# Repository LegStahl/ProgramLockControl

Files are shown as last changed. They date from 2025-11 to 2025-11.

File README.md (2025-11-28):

# ProgramLockControl
## Description
This device is supposed to use for controlling the door. It can open the door if the right IButton is pressed, also it has a button to open the door.
Device controls magnetic lock. Internally device can coolect info about opening the door, for example: key number, time of enter and etc.
Also device can another control high current till 5A load. This connection is supposed to be used for LED strip.
## Microcontroller and power schema V1.0
In the image below schema of the mcu and power.
<div style="text-align: center;">
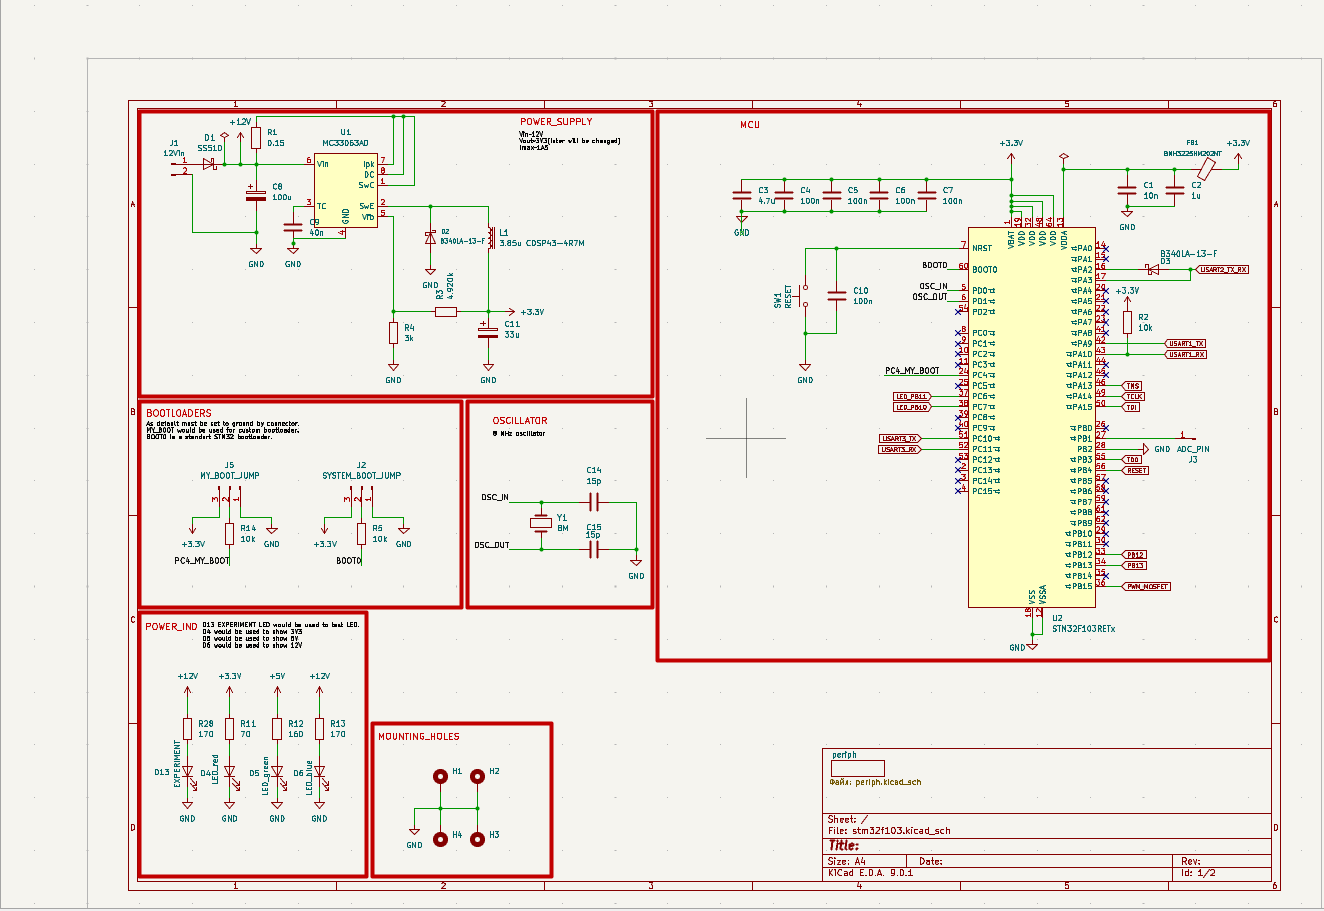
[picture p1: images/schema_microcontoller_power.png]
HTML Image
    
</div>

## Peripheria V1.0
In the image below schema of peripherias of MCU.
<div style="text-align: center;">
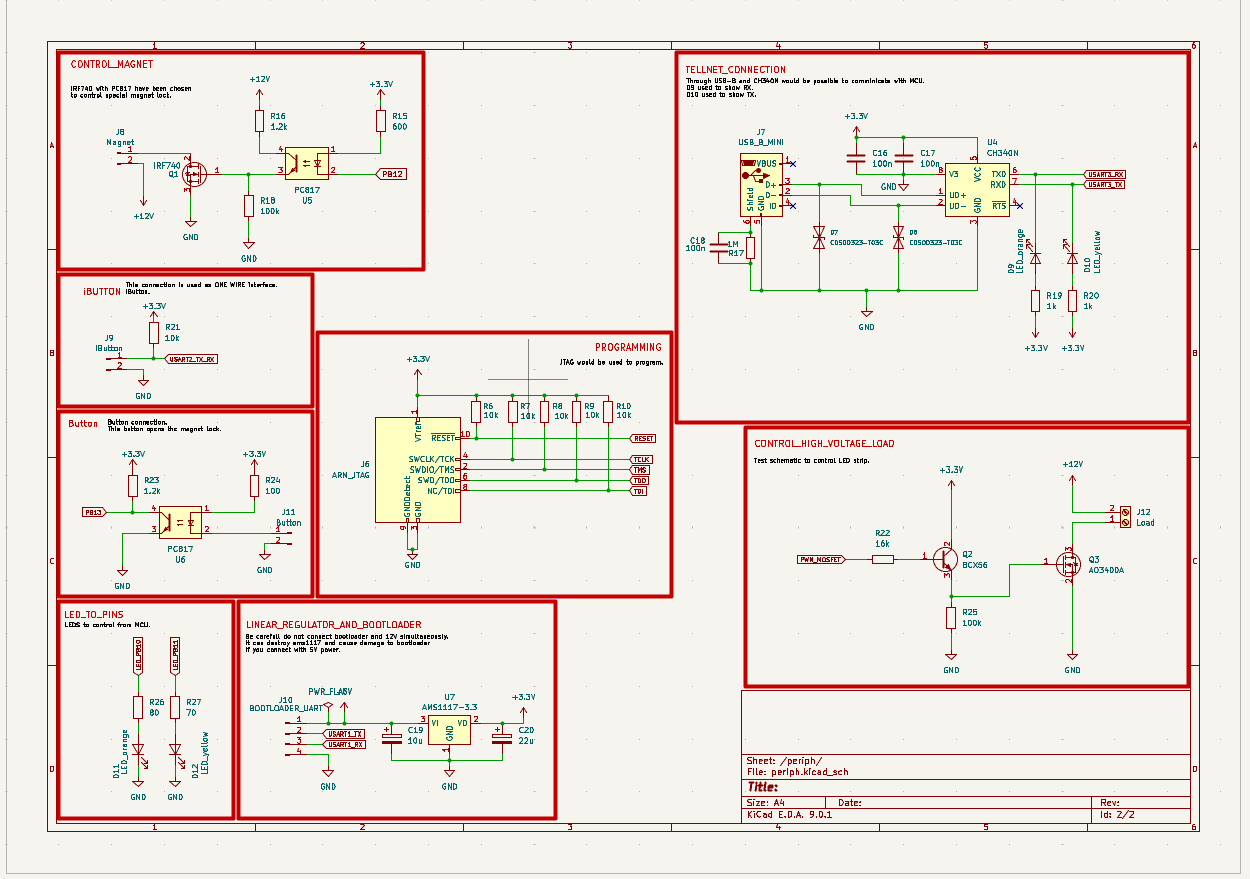
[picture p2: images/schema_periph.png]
HTML Image
    
</div>

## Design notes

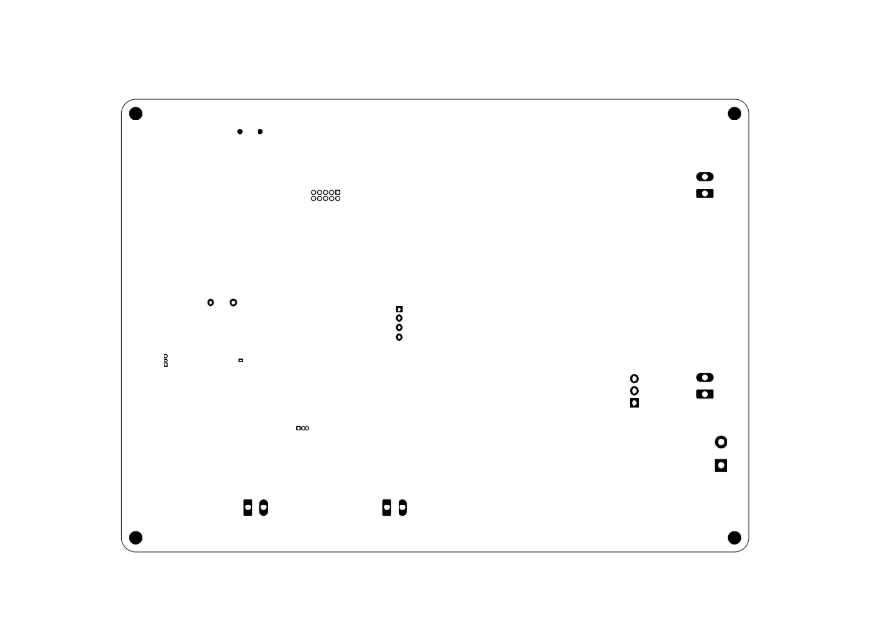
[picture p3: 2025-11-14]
images/Bottom_V1.png

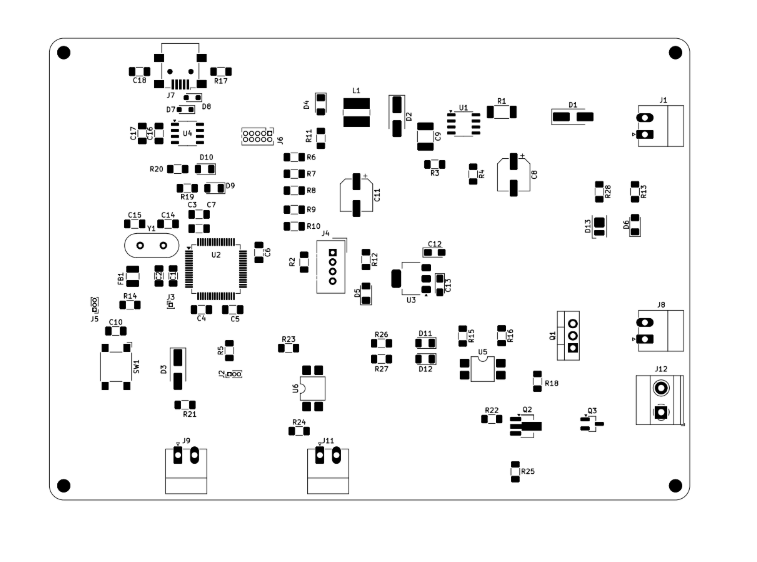
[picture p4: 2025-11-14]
images/Front_V1.png

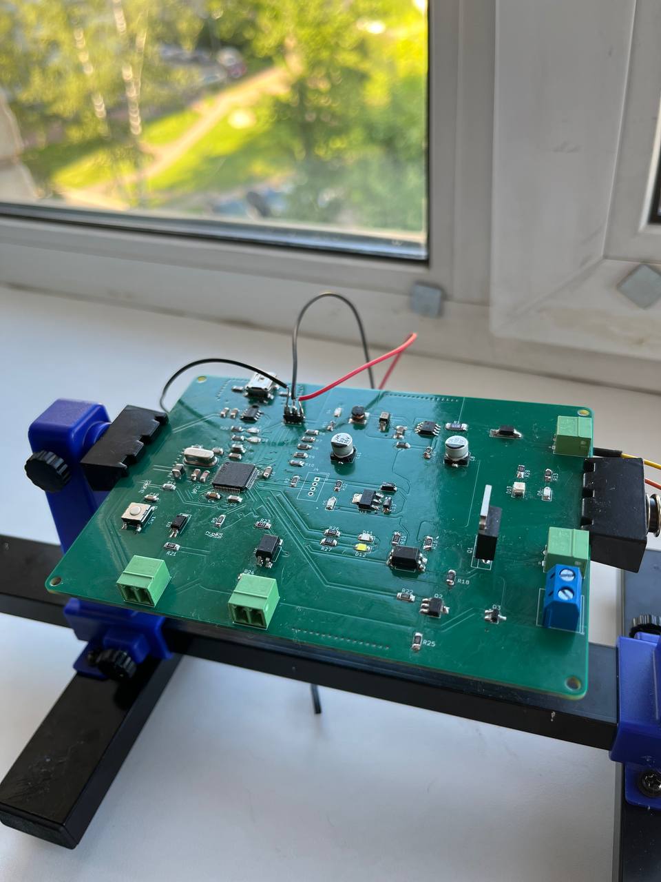
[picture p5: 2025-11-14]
images/device_V1.jpg

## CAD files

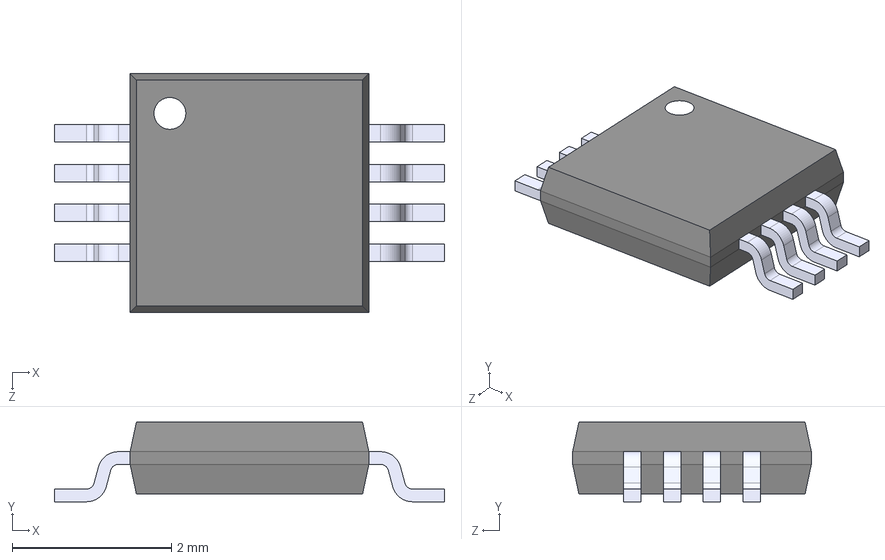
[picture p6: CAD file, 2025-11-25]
CH340N/CH340N.step
4.90 x 1 x 3.00 mm

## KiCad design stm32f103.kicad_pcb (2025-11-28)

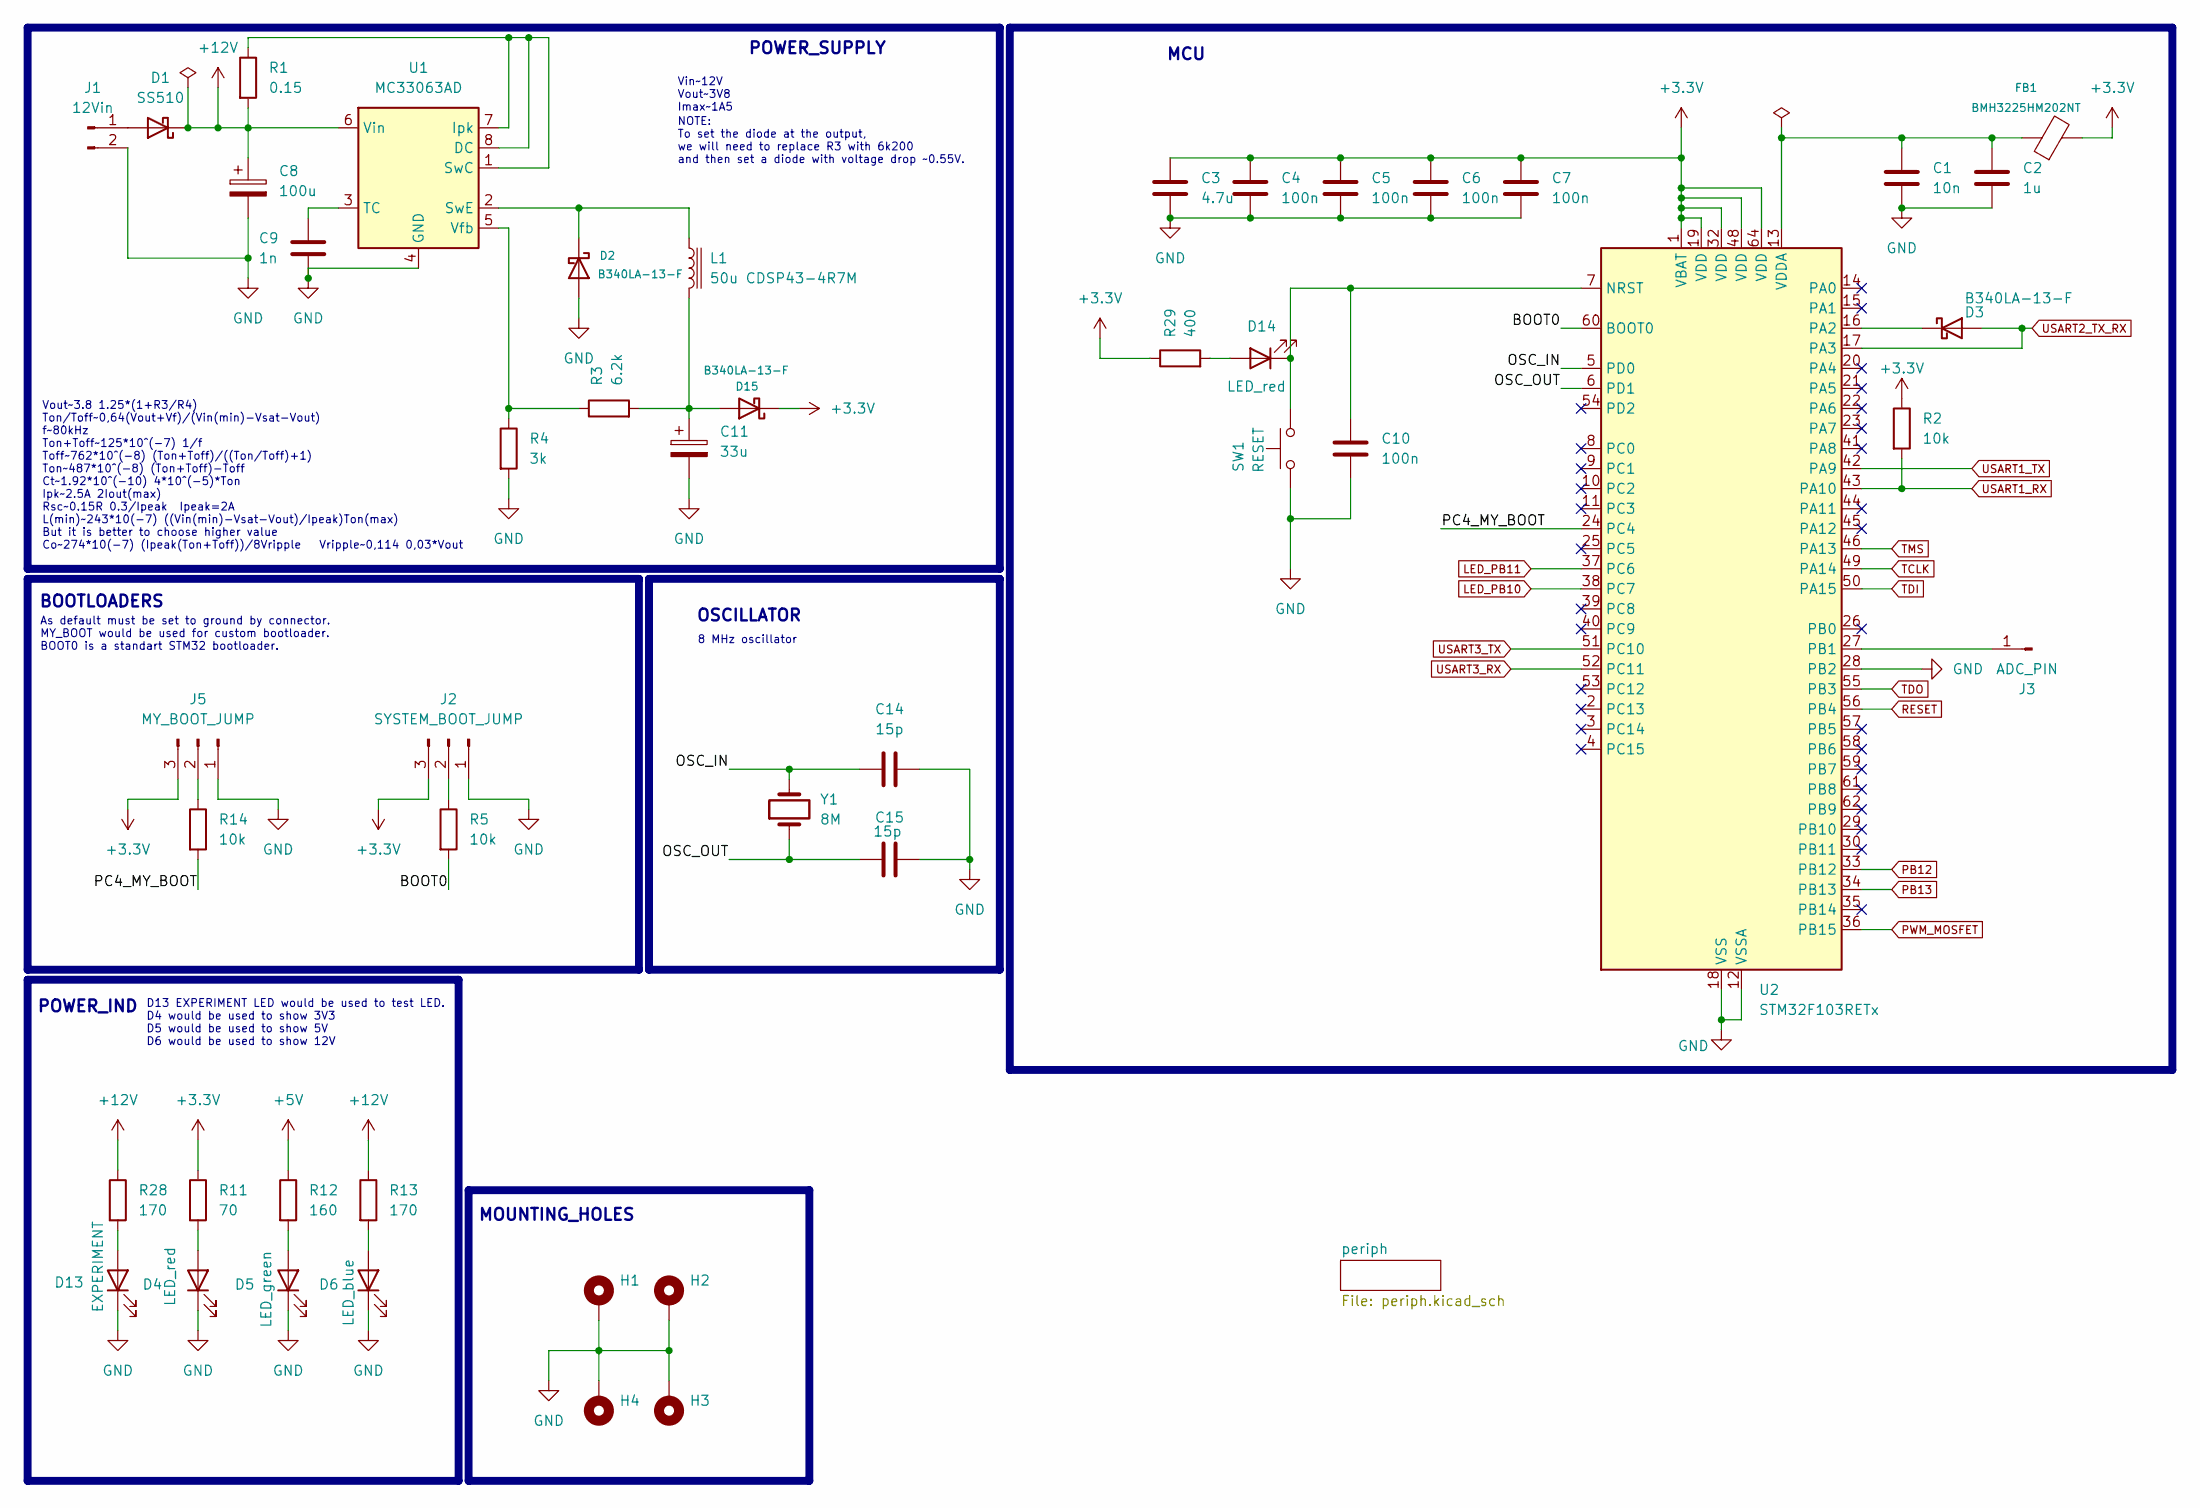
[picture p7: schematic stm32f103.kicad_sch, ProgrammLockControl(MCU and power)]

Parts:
C1: 10n; C_1206_3216Metric_Pad1.33x1.80mm_HandSolder
C2: 1u; C_1206_3216Metric_Pad1.33x1.80mm_HandSolder
C3: 4.7u; C_1206_3216Metric_Pad1.33x1.80mm_HandSolder
C4, C5, C6, C7, C10: 100n; C_1206_3216Metric_Pad1.33x1.80mm_HandSolder
C8: 100u; CP_Elec_6.3x5.4
C9: 1n; C_1812_4532Metric_Pad1.57x3.40mm_HandSolder
C11: 33u; CP_Elec_6.3x5.4
C14, C15: 15p; C_1206_3216Metric_Pad1.33x1.80mm_HandSolder
D1: SS510; D_SMA_Handsoldering
D2, D3, D15: B340LA-13-F; D_SMA_Handsoldering
D4, D14: LED_red; LED_1206_3216Metric_Pad1.42x1.75mm_HandSolder
D5: LED_green; LED_1206_3216Metric_Pad1.42x1.75mm_HandSolder
D6: LED_blue; LED_1206_3216Metric_Pad1.42x1.75mm_HandSolder
D13: EXPERIMENT; LED_Everlight-SMD3528_3.5x2.8mm_67-21ST
FB1: BMH3225HM202NT; L_1210_3225Metric_Pad1.42x2.65mm_HandSolder
H1, H2, H3, H4: MountingHole_Pad; MountingHole_3.2mm_M3_Pad_Via
J1: 12Vin; PhoenixContact_MC_1,5_2-G-3.5_1x02_P3.50mm_Horizontal
J2: SYSTEM_BOOT_JUMP; PinHeader_1x03_P2.54mm_Vertical
J3: ADC_PIN; PinHeader_1x01_P2.54mm_Vertical
J5: MY_BOOT_JUMP; PinHeader_1x03_P2.54mm_Vertical
L1: 50u CDSP43-4R7M; L_TracoPower_TCK-047_5.2x5.8mm
R1: 0.15; R_2010_5025Metric_Pad1.40x2.65mm_HandSolder
R2, R5, R14: 10k; R_1206_3216Metric_Pad1.30x1.75mm_HandSolder
R3: 6.2k; R_1206_3216Metric_Pad1.30x1.75mm_HandSolder
R4: 3k; R_1206_3216Metric_Pad1.30x1.75mm_HandSolder
R11: 70; R_1206_3216Metric_Pad1.30x1.75mm_HandSolder
R12: 160; R_1206_3216Metric_Pad1.30x1.75mm_HandSolder
R13, R28: 170; R_1206_3216Metric_Pad1.30x1.75mm_HandSolder
R29: 400; R_1206_3216Metric_Pad1.30x1.75mm_HandSolder
SW1: RESET; SW_SPST_Omron_B3FS-100xP
U1: MC33063AD; SO-8_3.9x4.9mm_P1.27mm
U2: STM32F103RETx; LQFP-64_10x10mm_P0.5mm
Y1: 8M; Crystal_HC49-4H_Vertical

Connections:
+3.3V: C3.1, C4.1, C5.1, C6.1, C7.1, D15.1 (K), FB1.2, J2.3, J5.3, R2.1, R11.1, R29.1, U2.1 (VBAT), U2.19 (VDD), U2.32 (VDD), U2.48 (VDD), U2.64 (VDD); also elsewhere on the board
+5V: R12.1; also elsewhere on the board
+12V: C8.1, D1.1 (K), R1.2, R13.1, R28.1, U1.6 (Vin); also elsewhere on the board
/BOOT0: R5.2, U2.60 (BOOT0)
/OSC_IN: C14.1, U2.5 (PD0), Y1.2
/OSC_OUT: C15.1, U2.6 (PD1), Y1.1
/PC4_MY_BOOT: R14.2, U2.24 (PC4)
GND: C1.2, C2.2, C3.2, C4.2, C5.2, C6.2, C7.2, C8.2, C9.2, C10.2, C11.2, C14.2, C15.2, D2.2 (A), D4.1 (K), D5.1 (K), D6.1 (K), D13.1 (K), H1.1, H2.1, H3.1, H4.1, J1.2, J2.1, J5.1, R4.2, SW1.1, U1.4 (GND), U2.12 (VSSA), U2.18 (VSS), U2.28 (PB2), U2.31 (VSS), U2.47 (VSS), U2.63 (VSS); also elsewhere on the board
LED_PB10: U2.38 (PC7); also elsewhere on the board
LED_PB11: U2.37 (PC6); also elsewhere on the board
unnamed: D1.2 (A), J1.1
unnamed: D2.1 (K), L1.1, U1.2 (SwE)
unnamed: D3.1 (K), U2.16 (PA2)
unnamed: D4.2 (A), R11.2
unnamed: D5.2 (A), R12.2
unnamed: D6.2 (A), R13.2
unnamed: D13.2 (A), R28.2
unnamed: D14.2 (A), R29.2
unnamed: C10.1, D14.1 (K), SW1.2, U2.7 (NRST)
unnamed: C11.1, D15.2 (A), L1.2, R3.2
unnamed: J2.2, R5.1
unnamed: J3.1, U2.27 (PB1)
unnamed: J5.2, R14.1
unnamed: R1.1, U1.1 (SwC), U1.7 (Ipk), U1.8 (DC)
unnamed: C9.1, U1.3 (TC)
unnamed: R3.1, R4.1, U1.5 (Vfb)
unnamed: C1.1, C2.1, FB1.1, U2.13 (VDDA)
PB12: U2.33 (PB12); also elsewhere on the board
PB13: U2.34 (PB13); also elsewhere on the board
PWM_MOSFET: U2.36 (PB15); also elsewhere on the board
RESET: U2.56 (PB4); also elsewhere on the board
TCLK: U2.49 (PA14); also elsewhere on the board
TDI: U2.50 (PA15); also elsewhere on the board
TDO: U2.55 (PB3); also elsewhere on the board
TMS: U2.46 (PA13); also elsewhere on the board
USART1_RX: R2.2, U2.43 (PA10); also elsewhere on the board
USART1_TX: U2.42 (PA9); also elsewhere on the board
USART2_TX_RX: D3.2 (A), U2.17 (PA3); also elsewhere on the board
USART3_RX: U2.52 (PC11); also elsewhere on the board
USART3_TX: U2.51 (PC10); also elsewhere on the board

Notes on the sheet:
Vin~12V Vout~3V8 Imax~1A5
MOUNTING_HOLES
D13 EXPERIMENT LED would be used to test LED. D4 would be used to show 3V3 D5 would be used to show 5V D6 would be used to show 12V
POWER_IND
MCU
NOTE: To set the diode at the output, we will need to replace R3 with 6k200 and then set a diode with voltage drop ~0.55V.
Vout~3.8 1.25*(1+R3/R4) Ton/Toff~0,64(Vout+Vf)/(Vin(min)-Vsat-Vout) f~80kHz Ton+Toff~125*10^(-7) 1/f Toff~762*10^(-8) (Ton+Toff)/((Ton/Toff)+1) Ton~487*10^(-8) (Ton+Toff)-Toff Ct~1.92*10^(-10) 4*10^(-5)*Ton Ipk~2.5A 2Iout(max) Rsc~0.15R 0.3/Ipeak Ipeak=2A L(min)~243*10(-7) ((Vin(min)-Vsat-Vout)/Ipe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
OSCILLATOR
BOOTLOADERS
As default must be set to ground by connector. MY_BOOT would be used for custom bootloader. BOOT0 is a standart STM32 bootloader.
POWER_SUPPLY
8 MHz oscillator

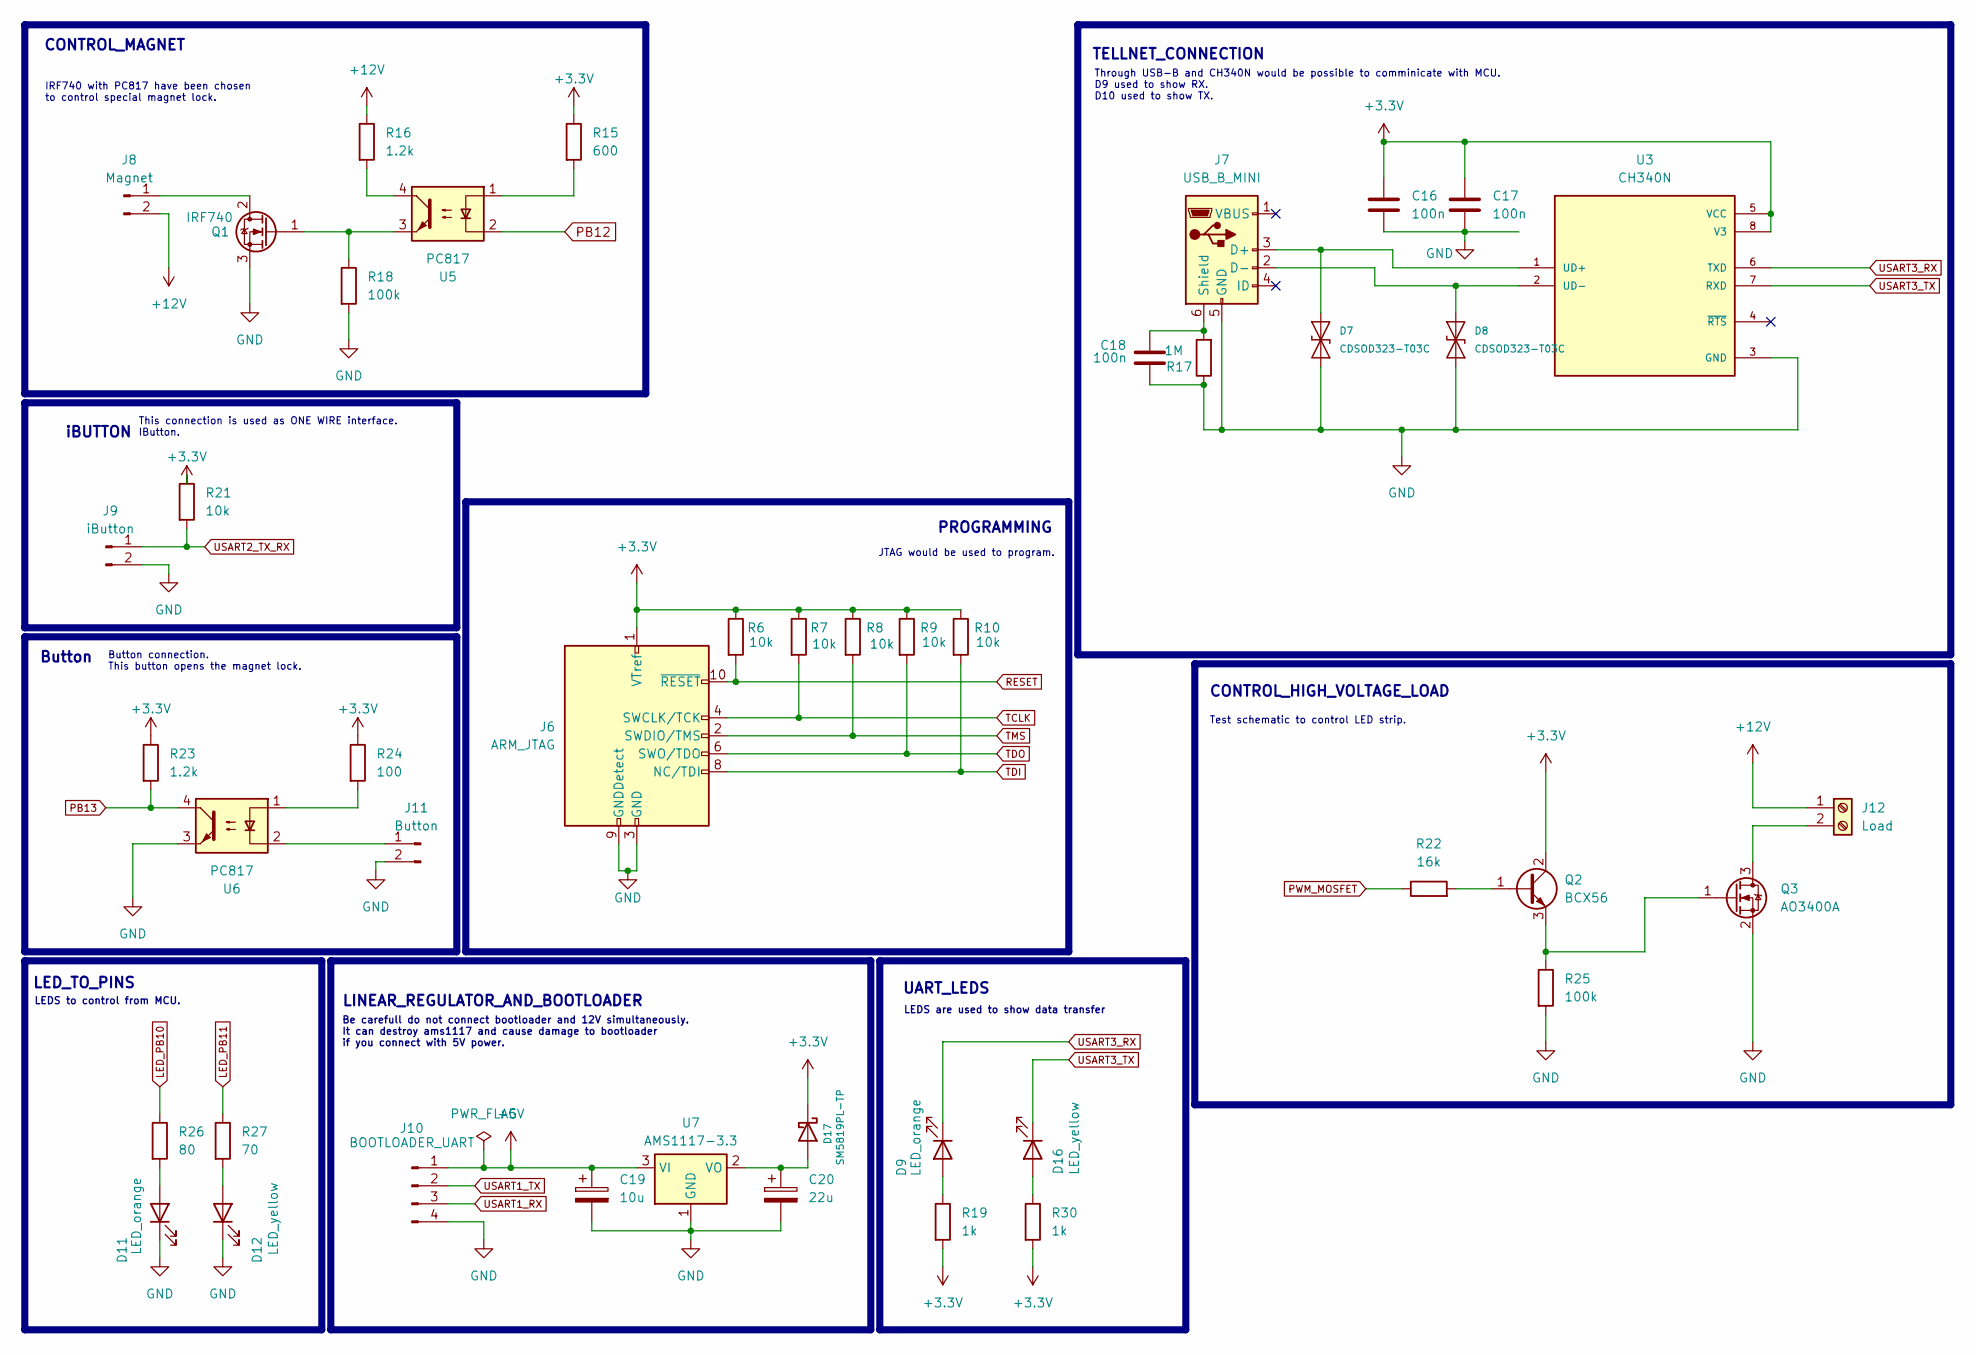
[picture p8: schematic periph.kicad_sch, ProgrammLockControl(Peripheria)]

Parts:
C16, C17, C18: 100n; C_1206_3216Metric_Pad1.33x1.80mm_HandSolder
C19: 10u; CP_EIA-3216-12_Kemet-S_HandSolder
C20: 22u; CP_EIA-3216-12_Kemet-S_HandSolder
D7, D8: CDSOD323-T03C; D_SOD-323_HandSoldering
D9, D11: LED_orange; LED_1206_3216Metric
D12, D16: LED_yellow; LED_1206_3216Metric
D17: SM5819PL-TP; D_SOD-123F
J6: ARM_JTAG; PinHeader_2x05_P2.54mm_Vertical
J7: USB_B_MINI; USB_Mini-B_Lumberg_2486_01_Horizontal
J8: Magnet; PhoenixContact_MC_1,5_2-G-3.5_1x02_P3.50mm_Horizontal
J9: iButton; PhoenixContact_MC_1,5_2-G-3.5_1x02_P3.50mm_Horizontal
J10: BOOTLOADER_UART; PinHeader_1x04_P2.54mm_Vertical
J11: Button; PhoenixContact_MC_1,5_2-G-3.5_1x02_P3.50mm_Horizontal
J12: Load; TerminalBlock_Phoenix_MKDS-1,5-2-5.08_1x02_P5.08mm_Horizont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
Q1: IRF740; TO-220-3_Vertical
Q2: BCX56; SOT-89-3_Handsoldering
Q3: AO3400A; SOT-23_Handsoldering
R6, R7, R8, R9, R10, R21: 10k; R_1206_3216Metric_Pad1.30x1.75mm_HandSolder
R15: 600; R_1206_3216Metric_Pad1.30x1.75mm_HandSolder
R16, R23: 1.2k; R_1206_3216Metric_Pad1.30x1.75mm_HandSolder
R17: 1M; R_1206_3216Metric_Pad1.30x1.75mm_HandSolder
R18, R25: 100k; R_1206_3216Metric_Pad1.30x1.75mm_HandSolder
R19, R30: 1k; R_1206_3216Metric_Pad1.30x1.75mm_HandSolder
R22: 16k; R_1206_3216Metric_Pad1.30x1.75mm_HandSolder
R24: 100; R_1206_3216Metric_Pad1.30x1.75mm_HandSolder
R26: 80; R_1206_3216Metric_Pad1.30x1.75mm_HandSolder
R27: 70; R_1206_3216Metric_Pad1.30x1.75mm_HandSolder
U3: CH340N; SOIC127P600X160-8N; PARTREV V3C
U5, U6: PC817; SMDIP-4_W7.62mm
U7: AMS1117-3.3; SOT-223-3_TabPin2

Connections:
+3.3V: C16.1, C17.1, D17.1 (K), J6.1 (VTref), Q2.2 (C), R6.1, R7.1, R8.1, R9.1, R10.1, R15.1, R19.2, R21.1, R23.1, R24.1, R30.2, U3.5 (VCC), U3.8 (V3); also elsewhere on the board
+5V: C19.1, J10.1, U7.3 (VI); also elsewhere on the board
+12V: J8.2, J12.1, R16.1; also elsewhere on the board
GND: C16.2, C17.2, C18.2, C19.2, C20.2, D7.1 (A1), D8.1 (A1), D11.1 (K), D12.1 (K), J6.3 (GND), J6.5 (GND), J6.9 (GNDDetect), J7.5 (GND), J9.2, J10.4, J11.2, Q1.3 (S), Q3.2 (S), R17.1, R18.2, R25.2, U3.3 (GND), U6.3, U7.1 (GND); also elsewhere on the board
LED_PB10: R26.1; also elsewhere on the board
LED_PB11: R27.1; also elsewhere on the board
unnamed: D7.2 (A2), J7.3 (D+), U3.1 (UD+)
unnamed: D8.2 (A2), J7.2 (D-), U3.2 (UD-)
unnamed: D9.2 (A), R19.1
unnamed: D11.2 (A), R26.2
unnamed: D12.2 (A), R27.2
unnamed: D16.2 (A), R30.1
unnamed: C20.1, D17.2 (A), U7.2 (VO)
unnamed: C18.1, J7.6 (Shield), R17.2
unnamed: J8.1, Q1.2 (D)
unnamed: J11.1, U6.2
unnamed: J12.2, Q3.3 (D)
unnamed: Q1.1 (G), R18.1, U5.3
unnamed: Q2.1 (B), R22.2
unnamed: Q2.3 (E), Q3.1 (G), R25.1
unnamed: R15.2, U5.1
unnamed: R16.2, U5.4
unnamed: R24.2, U6.1
PB12: U5.2; also elsewhere on the board
PB13: R23.2, U6.4; also elsewhere on the board
PWM_MOSFET: R22.1; also elsewhere on the board
RESET: J6.10 (~RESET), R6.2; also elsewhere on the board
TCLK: J6.4 (SWCLK/TCK), R7.2; also elsewhere on the board
TDI: J6.8 (NC/TDI), R10.2; also elsewhere on the board
TDO: J6.6 (SWO/TDO), R9.2; also elsewhere on the board
TMS: J6.2 (SWDIO/TMS), R8.2; also elsewhere on the board
USART1_RX: J10.3; also elsewhere on the board
USART1_TX: J10.2; also elsewhere on the board
USART2_TX_RX: J9.1, R21.2; also elsewhere on the board
USART3_RX: D9.1 (K), U3.6 (TXD); also elsewhere on the board
USART3_TX: D16.1 (K), U3.7 (RXD); also elsewhere on the board

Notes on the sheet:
Be carefull do not connect bootloader and 12V simultaneously. It can destroy ams1117 and cause damage to bootloader if you connect with 5V power.
CONTROL_MAGNET
LEDS to control from MCU.
Test schematic to control LED strip.
JTAG would be used to program.
Button
LED_TO_PINS
TELLNET_CONNECTION
IRF740 with PC817 have been chosen to control special magnet lock.
Button connection. This button opens the magnet lock.
Through USB-B and CH340N would be possible to comminicate with MCU. D9 used to show RX. D10 used to show TX.
UART_LEDS
LINEAR_REGULATOR_AND_BOOTLOADER
LEDS are used to show data transfer
PROGRAMMING
iBUTTON
This connection is used as ONE WIRE interface. IButton.
CONTROL_HIGH_VOLTAGE_LOAD

Board: 4 copper layers, 91 parts (0 on the bottom side), 57 nets, no tracks yet.

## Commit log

2025-11-13 First PCB project was done before git commits version:1.0
    [periph.kicad_sch, stm32f103.kicad_pcb, stm32f103.kicad_sch]
2025-11-14 Some rearrangements have been made in schematics
    [periph.kicad_sch, stm32f103.kicad_sch]
2025-11-14 Frames in schematics has been added. Types of mounting holes has been replaced
    [periph.kicad_sch, stm32f103.kicad_sch]
2025-11-14 Comments have been added to the schemas
    [periph.kicad_sch, stm32f103.kicad_sch]
2025-11-19 Images of schema has been added and some components value has been changed@
    [stm32f103.kicad_sch]
2025-11-20 Footprints of bootloaders and boots have been changed also has been cahnged ADC pin header, reset LED have been added, and diode for switch
    [periph.kicad_sch, stm32f103.kicad_sch]
2025-11-25 Calculations have been made for MC33063 with diode at the output
    [stm32f103.kicad_sch]
2025-11-25 CH340N has been added. Previous version was wrong. Pin V3 was wrong placed and was connected to GND
    [CH340N.step, periph.kicad_sch, stm32f103.kicad_sch]
2025-11-28 Stack has been chosen: 4 layer SIG+GND+PWR+SIG. Componetns have been divided in groups pcb
    [stm32f103.kicad_pcb]
2025-11-28 Shottky diod has been added to provide protection for AMS1117-3.3
    [periph.kicad_sch, stm32f103.kicad_pcb, stm32f103.kicad_sch]
